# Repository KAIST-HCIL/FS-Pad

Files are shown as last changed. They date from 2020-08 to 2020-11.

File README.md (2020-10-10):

# FS-Pad
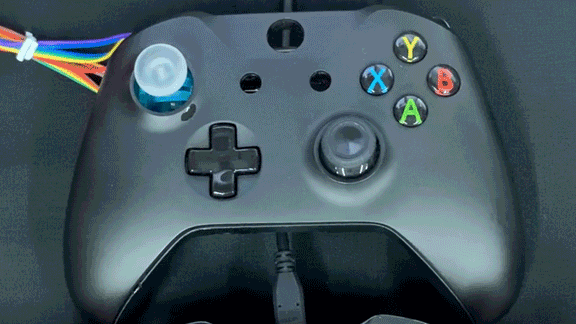
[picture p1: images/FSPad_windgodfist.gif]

<br>
**FS-Pad** is a gamepad with a force feedback thumbstick module.
<br>
You can now feel the external force through your hands when your car crashes, when your avatar gets attacked by an enemy, or when you fire a giant bazooka.
<br>
This is an open source project. Anyone can customize, test, and play with these tiny modules.

  - Video preview: https://youtu.be/CJSe5nMkmYE
  - Game interactions video: https://youtu.be/d1z8tTswZFI
  
This work was presented in [UIST 2020](https://uist.acm.org/uist2020/). You could check out game interaction scenarios & device specification on the paper.

[[Paper]](/FS-Pad.pdf)

## FS Module
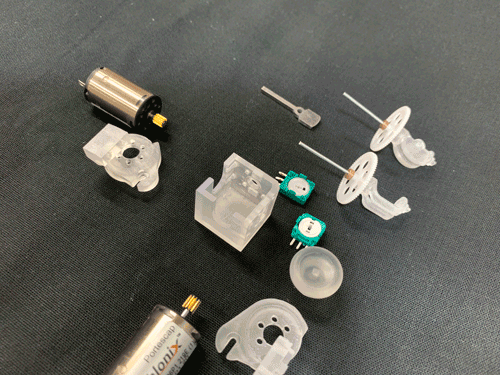
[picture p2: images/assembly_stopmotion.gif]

<br>
Force feedback thumbstick module. The core of the FS-Pad.
<br>
**[Assembly guide](/Assembly%20guide.md)**

## Circuitry
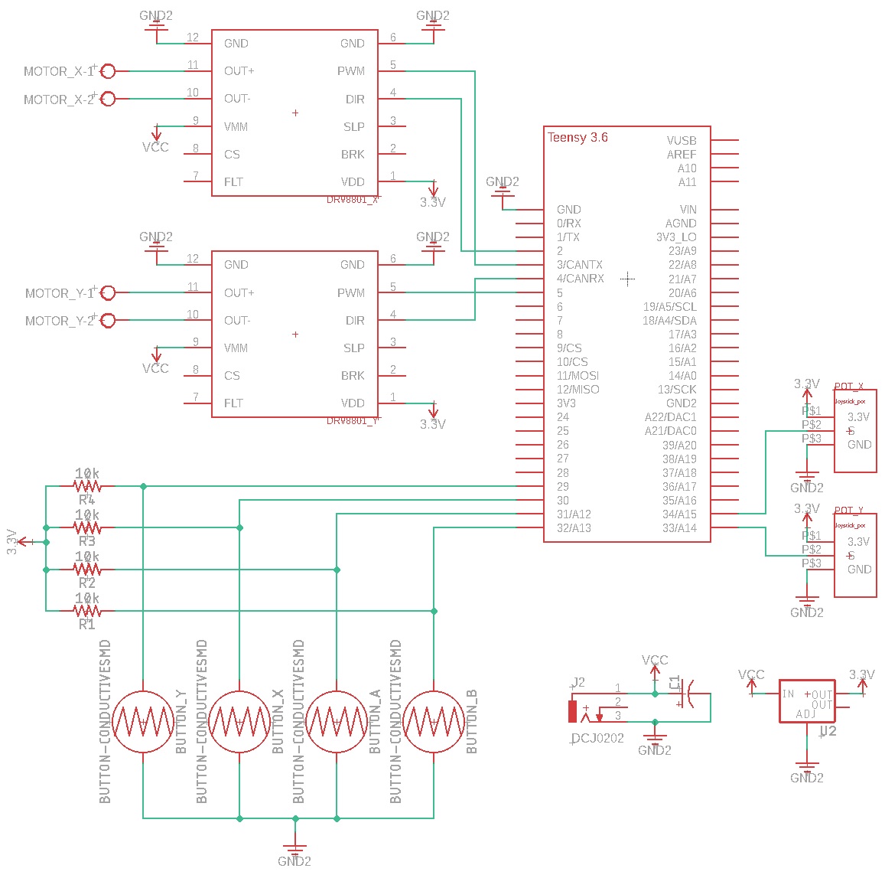
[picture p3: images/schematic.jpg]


  - **Components needed**
    + Teensy 3.6
    + 2 * Motor driver (DRV8801 Breakout board) [[Site]](https://www.pololu.com/product/2136/resources)
    + DC power jack
    + Voltage regulator (LM1117)
    + 4 * 10k Ohm resistors
    + 1 mF capacitor
  - **[Schematic](/circuitry/FSPad_sch.sch)** (Created with Autodesk EAGLE)

## Firmware
**[firmware.ino](/firmware/firmware.ino)**
* Upload the firmware through [Teensyduino](https://www.pjrc.com/teensy/td_download.html).
* You could find out some test scripts and explanations in the [firmware directory](/firmware).

## Announcement
We are currently building a bi-manual version of the FS-Pad; including exclusive housing, custom PCB & schematic, and easy-to-follow documentations. If you have any requests or questions, please directly contact us.

youngbo.shim@kaist.ac.kr

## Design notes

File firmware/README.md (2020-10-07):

# FS-Pad Teensy 3.6 firmware

## Upload the firmware
Upload the firmware to your Teensy through [Teensyduino](https://www.pjrc.com/teensy/td_download.html).

## Calibrating position
Once you set up the hardware, you should update the potentiometer range in the firmware.
- In *firmware.ino*, set *debugMode* as *DEBUG_STICK*
- Open Arduino's Serial monitor.
- Check the raw potentiometer values (0~1023). Record the min/max values of X/Y axes inside your HW configuration's workspace.
- In *firmware.ino*, modify the parameters: *minX, maxX, minY, maxY*.

## Map Test

The map test code [test_forcemaps.py](test_forcemaps.py) can make various kinds of force maps. It shows visualization of a force map and sends it to the Teensy board.

### Quick Start
Below is an example of simulating a spring thumbstick on the FS-Pad.

Be sure to use your port number instead of COM26.

Windows:
```console
$ python -m venv venv
$ venv\Scripts\activate
(venv) $ python -m pip install -r requirements.txt
(venv) $ python .\test_forcemaps.py -f 60 -t spring -p COM26
```
Output:
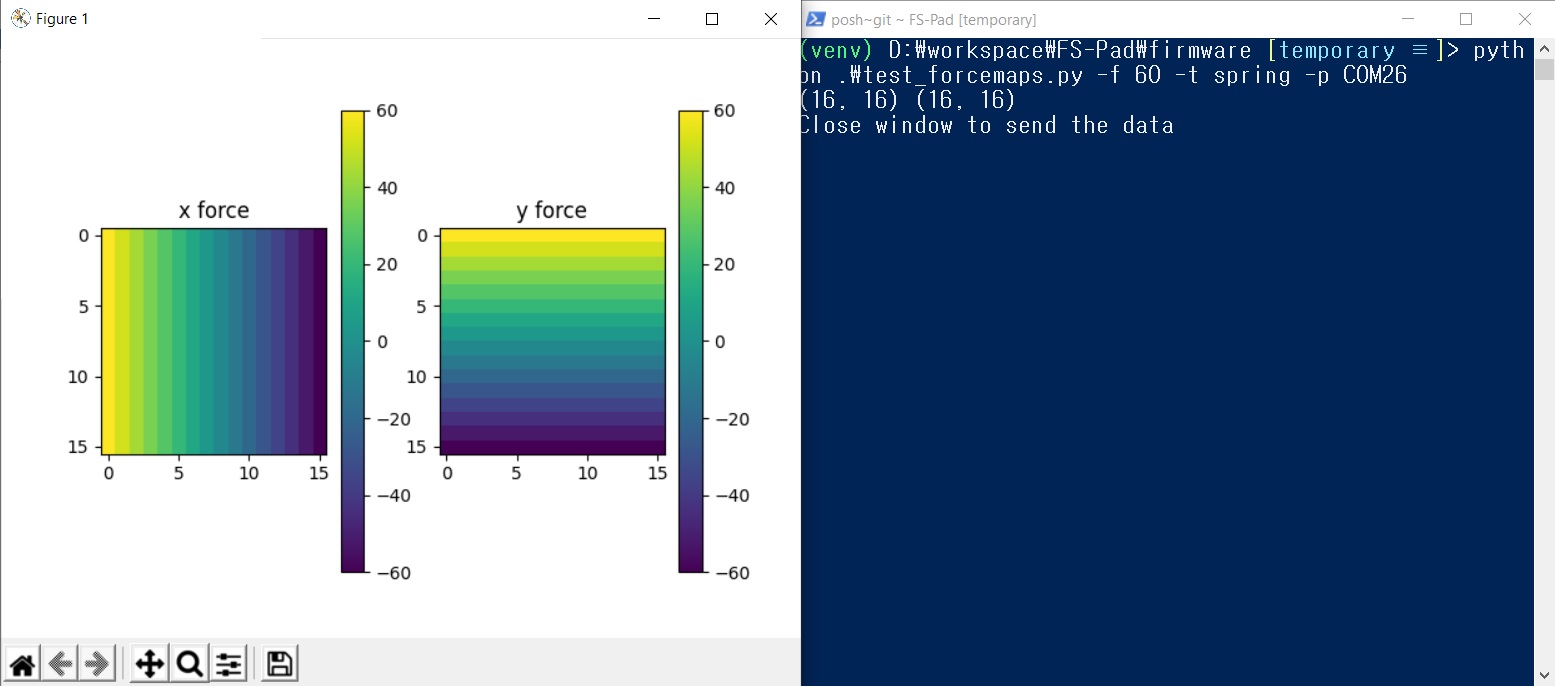
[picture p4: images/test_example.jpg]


You can directly setup your environment instead of using [venv](https://docs.python.org/3/tutorial/venv.html).

## Data format
Every data packet should have a mode indicator byte at the beginning. 'm' is for force map update and 'p' is for force point update.

### Force map
Data should be send as follows. *F* is a list of bytes that contains all data of a force map. *X* is a force map of x direction values and *Y* is for y direction.
Therefore, the size of X and Y is '*# of grid X # of grid*'.
```python
F[0] = X[0,0]
F[1] = Y[0,0]
F[2] = X[0,1]
F[3] = Y[0,1]
.
.
.
F[2*(i*n + j)] = X[i,j]
F[2*(i*n + j)+1] = Y[i,j]
```
The length of F is '*# of grid X # of grid X 2*'. If F is converted to a byte array, the size would be '*# of grid X # of grid X 2 X 4*'. **sizeof(int) == 4 for both Teensy and python**. Teensy reads '*# of grid X # of grid X 2 X 4*' length of bytes when a serial buffer is filled.

If you are not sure how to send data, please see [test_data_send.py](test_data_send.py) or [test_forcemaps.py](test_forcemaps.py).

### Force point
A packet should have the following three values in order.
- force value of x direction
- force value of y direction
- whether to use a saved force map or not (0 = not use, 1 = use)

## Troubleshooting
### Out of RAM
```shell
/home/keunwoo/arduino-1.8.9/arduino-1.8.9/hardware/tools/arm/bin/../lib/gcc/arm-none-eabi/5.4.1/../../../../arm-none-eabi/bin/ld: /tmp/arduino_build_569459/firmware.ino.elf section `.bss' will not fit in region `RAM'
/home/keunwoo/arduino-1.8.9/arduino-1.8.9/hardware/tools/arm/bin/../lib/gcc/arm-none-eabi/5.4.1/../../../../arm-none-eabi/bin/ld: region `RAM' overflowed by 4208 bytes
collect2: error: ld returned 1 exit status
Error compiling for board Teensy 3.6.
```
If you see this kind of error, assign global arrays to *static* ([ref](https://forum.pjrc.com/archive/index.php/t-24449.html)).

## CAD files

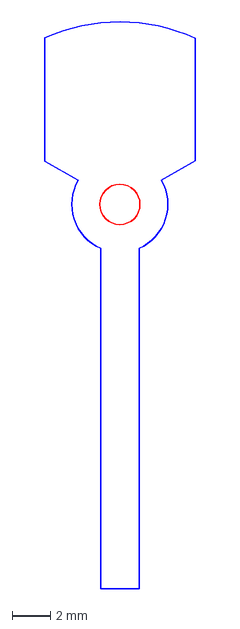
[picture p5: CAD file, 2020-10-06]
CAD files/Stick.dxf
7.82 x 29.8 mm

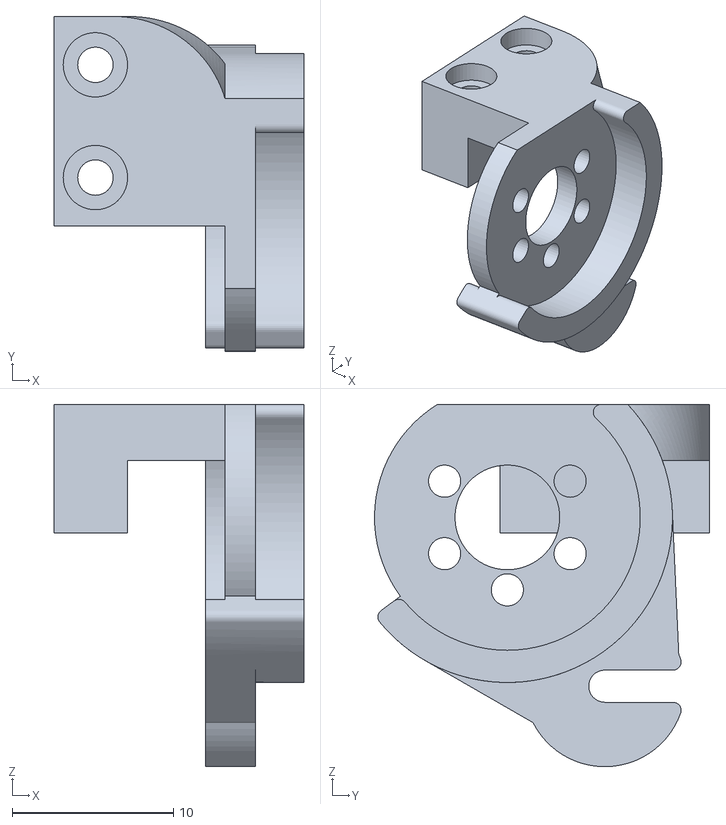
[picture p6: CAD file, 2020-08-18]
CAD files/X axis motor mount.stl
15.5 x 20.8 x 22.5

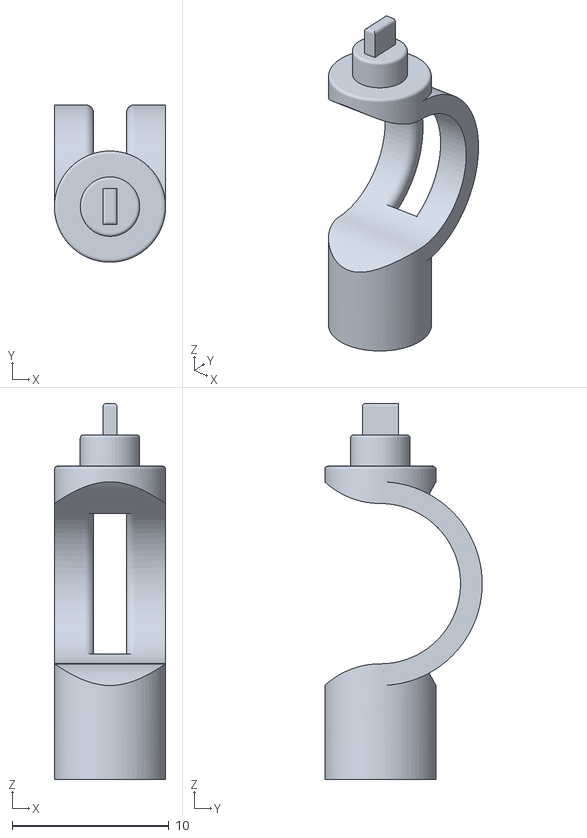
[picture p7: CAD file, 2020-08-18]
CAD files/Y axis guide.stl
7.10 x 10.0 x 24.0

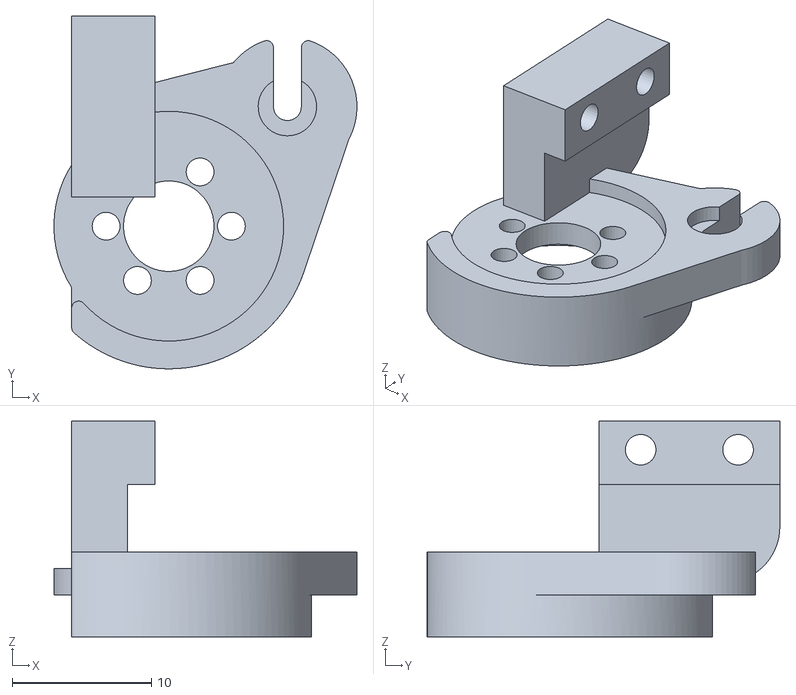
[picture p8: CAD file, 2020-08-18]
CAD files/Y axis motor mount.stl
21.8 x 25.3 x 15.5

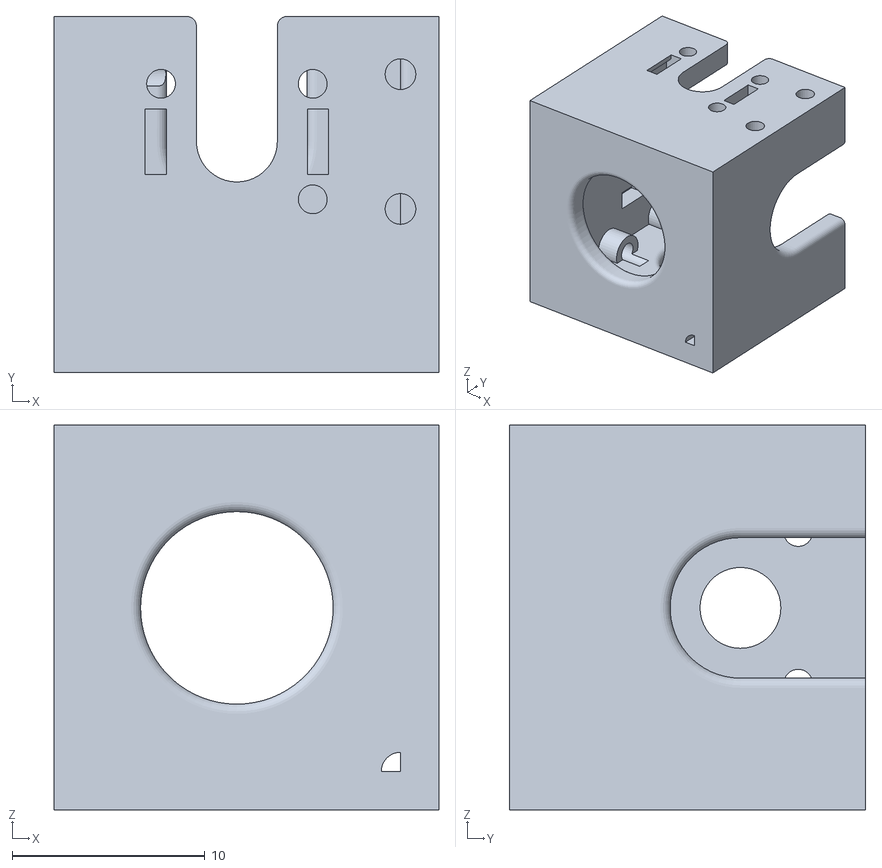
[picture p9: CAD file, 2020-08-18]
CAD files/Module body.stl
20.0 x 18.5 x 20.0

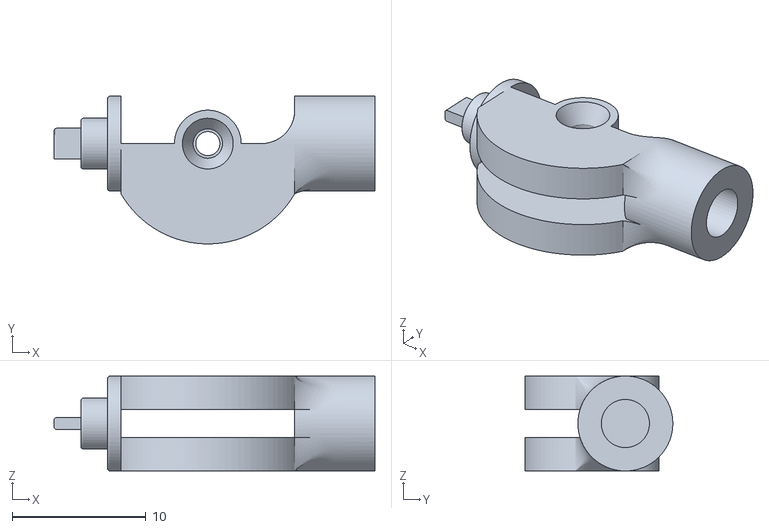
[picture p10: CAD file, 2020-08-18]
CAD files/X axis guide.stl
24.0 x 11.0 x 7.10

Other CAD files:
CAD files/FS Module.f3d

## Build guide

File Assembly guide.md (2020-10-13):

# FS module assembly guide
## Preparation
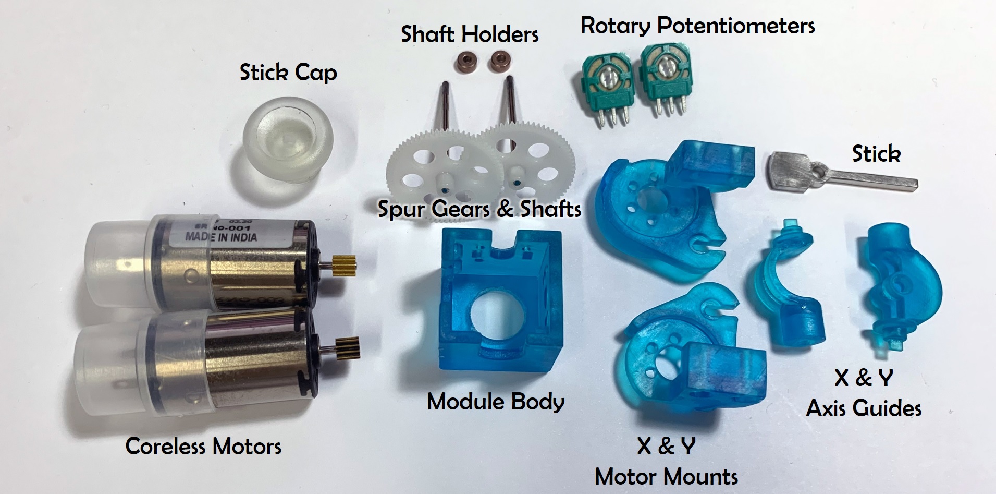
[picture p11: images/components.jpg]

- **Components needed**<br>
Modifying the components will require you to directly modify the CAD files to fit the 3D printable parts.
  + 2 * Coreless motor (16DCT Athlonix 219E) [[Site]](https://www.portescap.com/en/products/brush-dc-motors/athlonix-motors/16dct-athlonix-precious-metal-brush-dc-motor)
  + 2 * Rotary potentiometer (Took apart from a Xbox One controller's thumbstick module)
  + 2 * Large spur gear (70 teeth, modulus 0.3, diameter 21.45 mm, width 1.2 mm) [[Site]](https://ko.aliexpress.com/item/4000099888614.html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,scm-url:1007.14976.178076.0,pvid:82aaac0b-55b4-41d3-aa16-17b92ed123fd,tpp_buckets:668%230%23131923%2358_668%23808%237756%23631_668%23888%233325%2317_4976%230%23178076%230_4976%232711%237538%23352_4976%233223%2310815%237_4976%233104%239653%235_4976%233141%239887%234_668%232846%238116%23949_668%232717%237561%23318__668%233422%2315392%23468)
  + 2 * Small spur gear (11 teeth, modulus 0.3, diameter 3.9 mm, width 4 mm) [[Site]](https://www.aliexpress.com/item/33023736047.html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,searchweb201602_,searchweb201603_)
  + 2 * Shaft M1.5
  + 2 * Shaft holder M1.5
  + 6 * Bolt M1.6 (2.5 mm)
  + 4 * Bolt M2 (10 mm)

<br>

- **Printable parts**<br>
We used a SLA 3D printer ([Form 3](https://formlabs.com/3d-printers/form-3/)). Parts are printed with Tough resin (which is deprecated now by Formlabs) at 0.05 mm resolution. If you use different 3D printers with different settings, you may need some modifications on the CAD file to make a perfect fit for the assembly. Intensive stress is applied to these parts during actuation, so we recommend to use the most durable engineering material for your 3D printer. You could either directly use the .stl files below or export models into printable formats from the Fusion 360 file.
  + [Module body](/CAD%20files/Module%20body.stl)
  + [X axis guide](/CAD%20files/X%20axis%20guide.stl)
  + [X axis motor mount](/CAD%20files/X%20axis%20motor%20mount.stl)
  + [Y axis guide](/CAD%20files/Y%20axis%20guide.stl)
  + [Y axis motor mount](/CAD%20files/Y%20axis%20motor%20mount.stl)
  + **[CAD file](/CAD%20files/FS%20Module.f3d)** (Created with Autodesk Fusion 360)

<br>

- **Stick - laser cut**<br>
We laser cut stainless steel to produce sticks with low friction and durability. You should grind the sharp edges to fit the stick with the components before assembly.
  + [Stick](/CAD%20files/Stick.dxf) (.dxf file)

<br>

- **Tools**<br>
You may need tools listed below while assembling the parts.
  + Screwdriver
  + Tapping tool
  + Rotary tool
  + Instant glue
  + Sandpaper

<br>

## Assembling process
  1. Use the tap to make threads on the module body and X axis guide as indicated below.
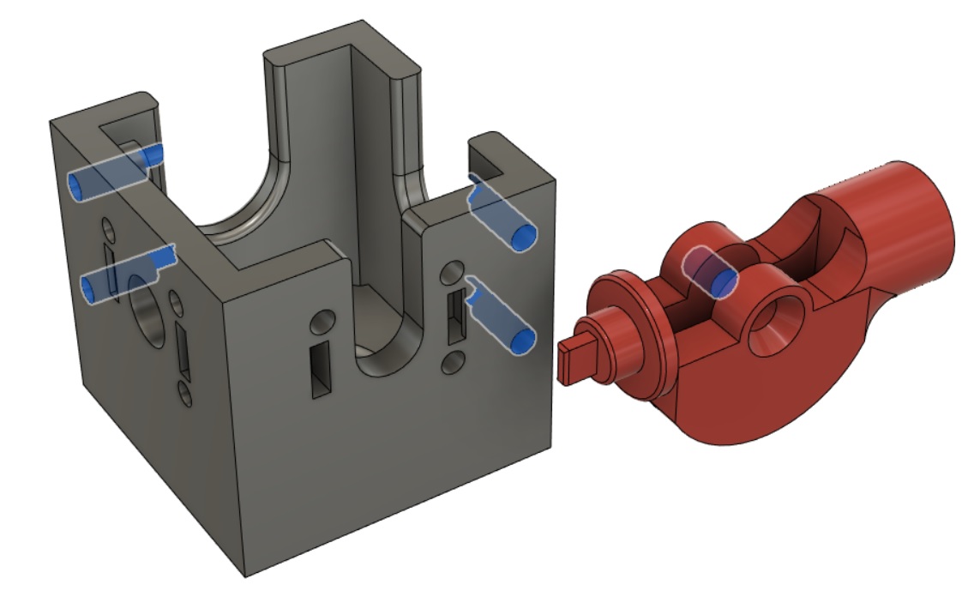
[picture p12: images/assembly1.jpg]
Module body and X axis guide with thread holes indicated.
  
  2. Stick the shafts with the large spur gears, and then attach the gears with the axes guide parts. Note that aligning the shaft and the guide part is important, since this determines the inner friction.
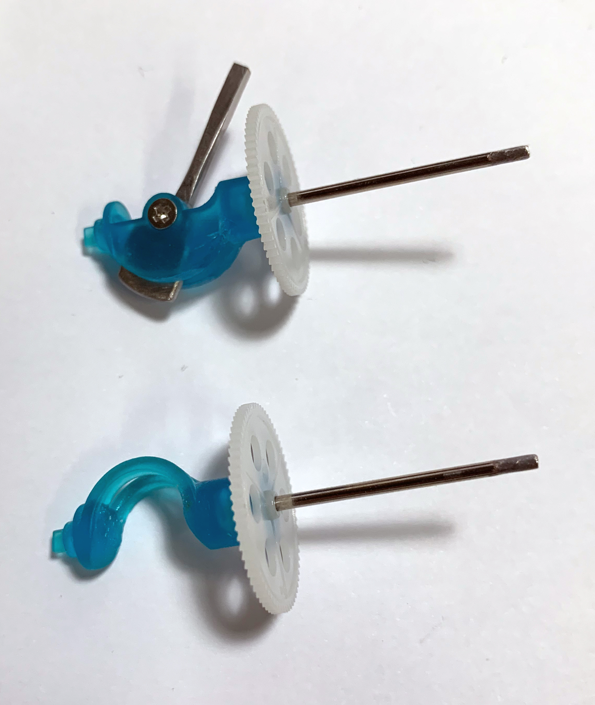
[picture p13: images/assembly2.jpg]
Axes guide parts with large spur gears attached.
  
  3. Install the stick inside the X axis guide (7mm flat M2 bolt). Ensure that the stick moves freely with minimum friction. Try to loosen the bolt or grind the stick if the stick hardly moves.
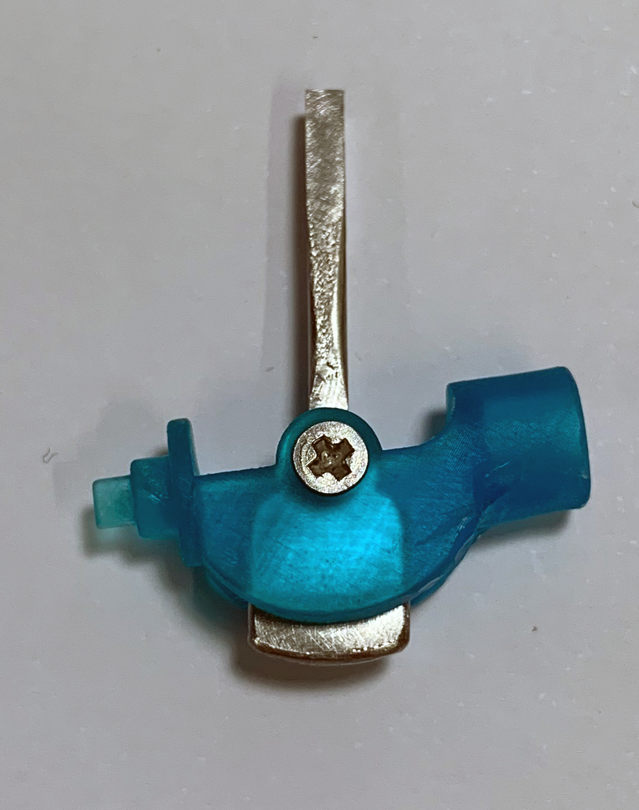
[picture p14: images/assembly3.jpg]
Stick placing inside the X axis guide part.
  
  4. Cross the axes guide parts and fit into the module body.
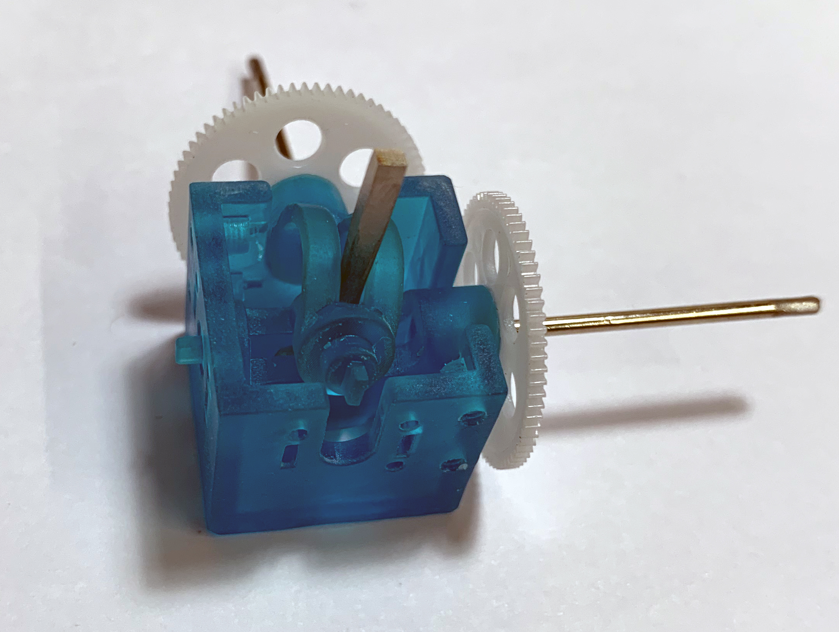
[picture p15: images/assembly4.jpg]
Axes guides fit inside the module body.
  
  5. Push in the potentiometers until they click into the module body. Check if the tips of the axes guides are well inserted.
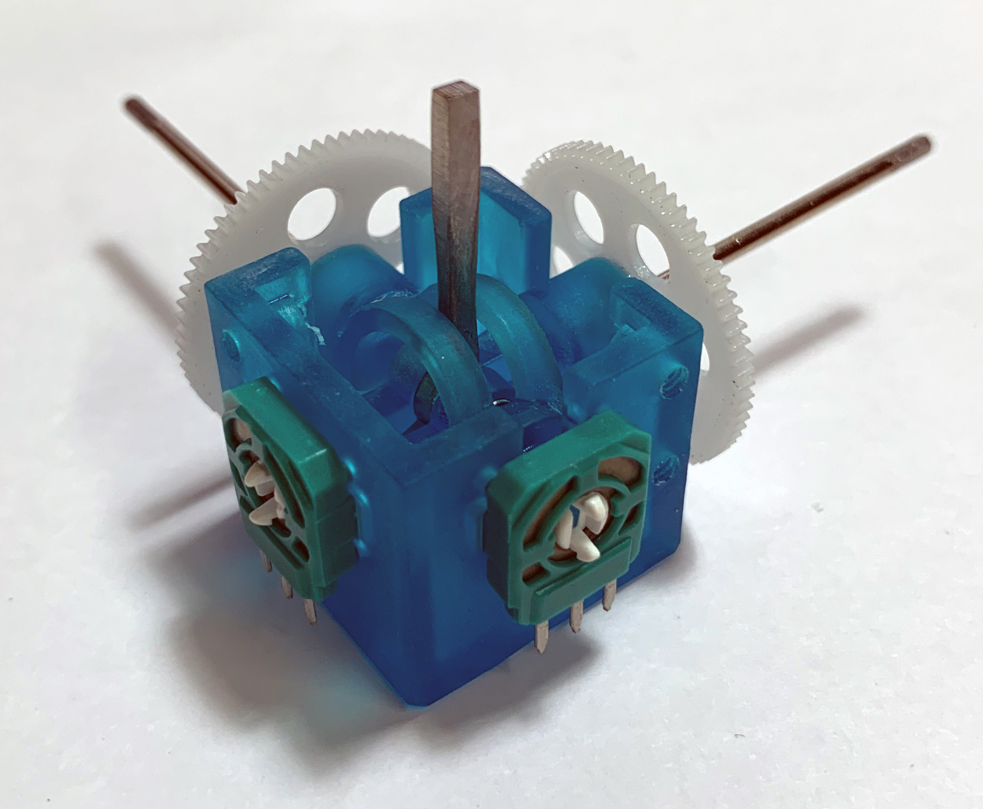
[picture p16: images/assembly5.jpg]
Module body with the potentiometers attached.
  
  6. Connect the motors with the motor mounts (M1.6 bolts).
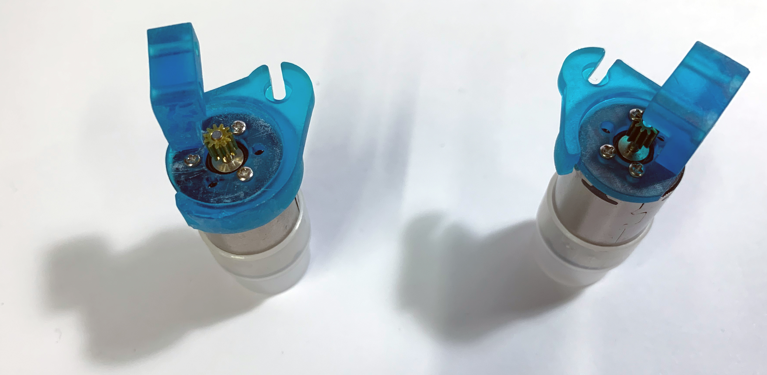
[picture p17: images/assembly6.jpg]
Two motors with motor mounts attached for each.
  
  7. Put the shaft holders first.
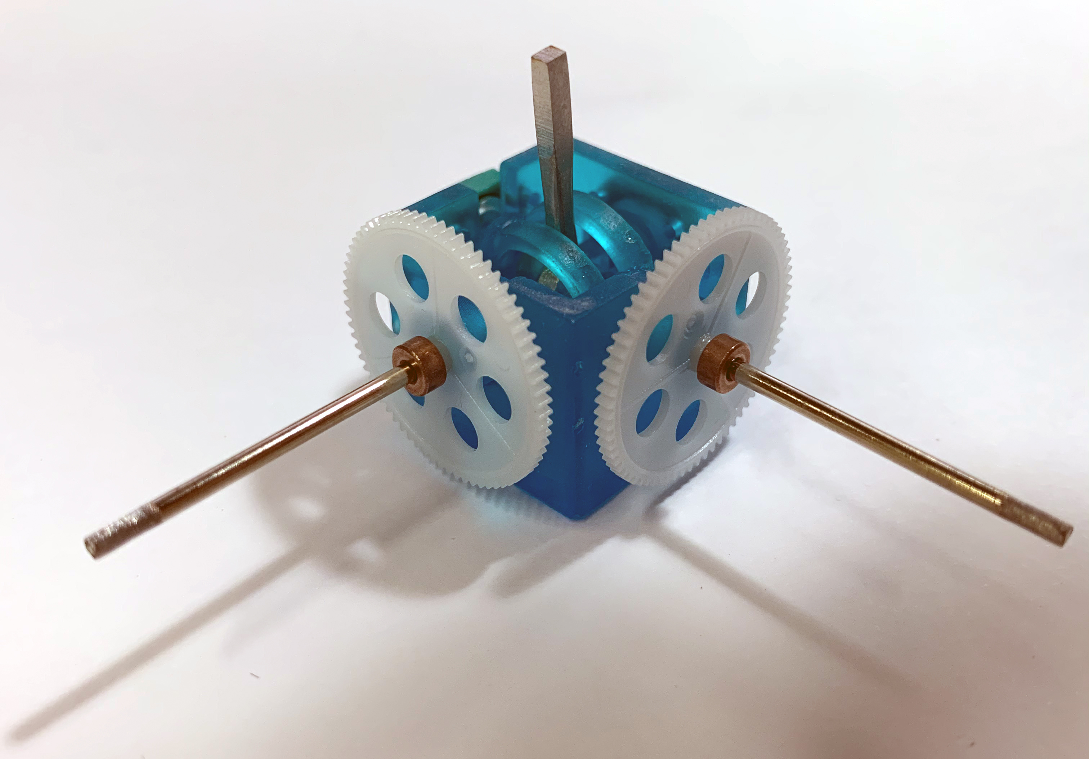
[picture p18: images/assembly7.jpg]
Shaft holders put on the shafts.
  
  8. Connect the motor mounts with the module body (M2 bolts). Check if the stick moves smoothly inside the working space (It may get stuck in diagonal border area inside the module body, but it's OK since the stick won't use that area during actuation).
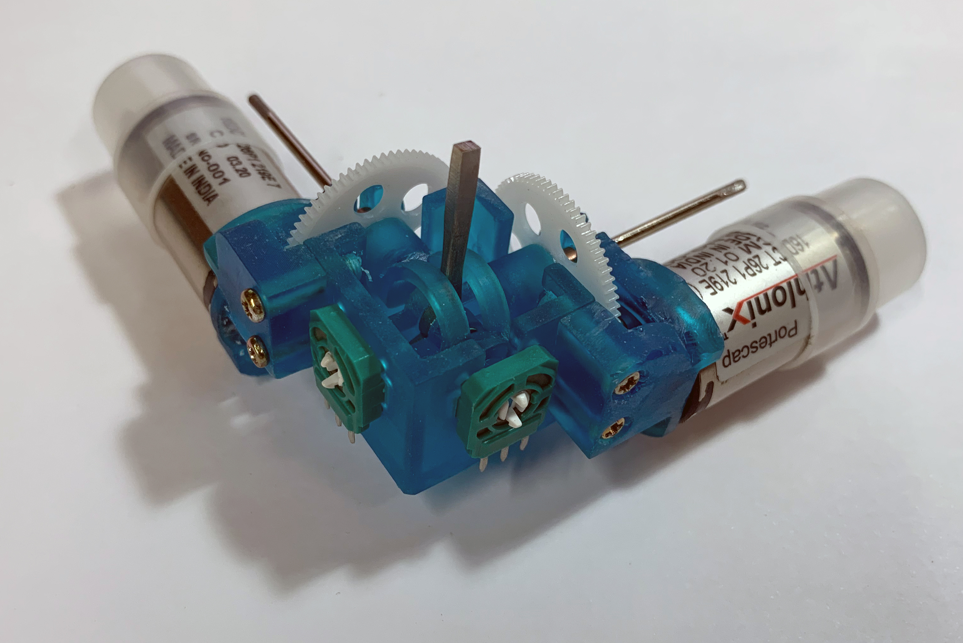
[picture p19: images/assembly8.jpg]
Module body and motors connected.
  
  9. Put the stick cap on.
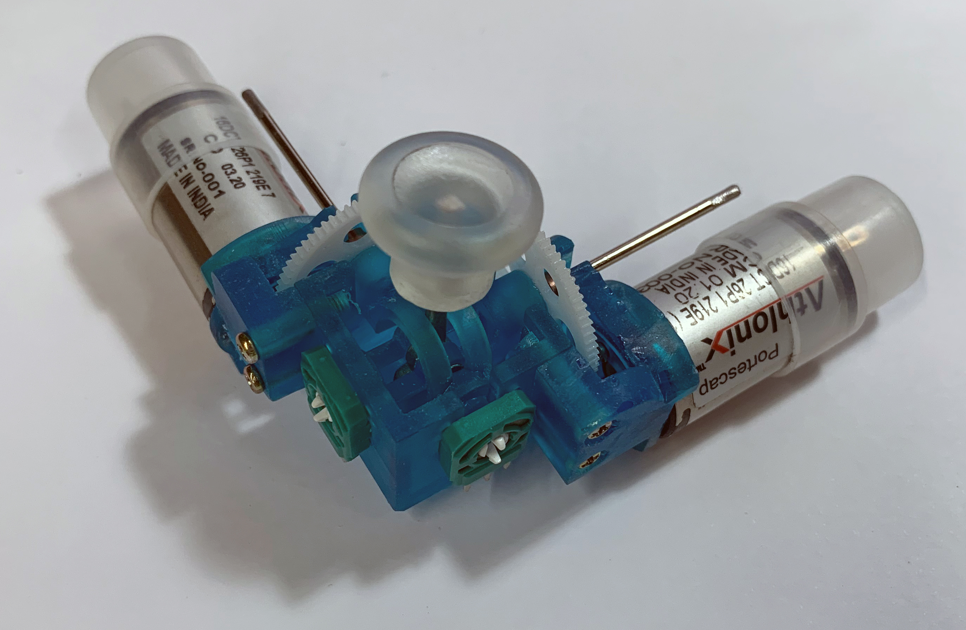
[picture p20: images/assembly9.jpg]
Stick cap added on the module body's stick.


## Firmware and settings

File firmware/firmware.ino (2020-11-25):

#define NO_DEBUG 0
#define DEBUG_RW 1
#define DEBUG_STICK 2
#define SPEED_TEST 3
/*
 ********* PARAMS TO SET*************
*/

const int numGrid = 16;
const int debugMode = NO_DEBUG; // 0: no debug, 1: read/write debug, 2: stick debug
const float minX = 763.0;
const float maxX = 349.0;
const float minY = 686.0;
const float maxY = 240.0;
const float motorXGain = 1.0; // Scales the final output of motor X to balance both motors
const float motorYGain = 0.6; // Scales the final output of motor Y to balance both motors

/**************************/


#include <math.h>

const int vcaXP = 2; // forward vs backward
const int vcaXE = 3; // power (PWM)
const int potXPin = A15;
const int vcaYP = 4; // forward vs backward
const int vcaYE = 5; // power (PWM)
const int potYPin = A14;

// button pins
const int btnAPin = 31;
const int btnBPin = 32;
const int btnXPin = 30;
const int btnYPin = 29;


const int mapSize = numGrid * numGrid * 2 * sizeof(byte); // sizeof(byte) = 1 byte;
const int vectorSize = sizeof(byte) * 2;
const int numVectorInMap = mapSize / vectorSize;

typedef union force_map
{
  byte buf[mapSize];
  byte grid[numGrid][numGrid][2];
};

const int pointSize = sizeof(uint8_t) * 3;
typedef union force_point
{
  struct
  {
    byte x;
    byte y;
    byte useMap;
  } value;
  byte buf[pointSize];
};

static force_map forceMap;
static force_point forcePoint;

// code protocol
const char mapCode = 'm';
const char pointCode = 'p';
const char successCode = 's';

// value holders
int potXPos = 0;
int potYPos = 0;
int forceXP = 0;
int forceXE = 0;
int forceYP = 0;
int forceYE = 0;
int stickMode = 1;
// posistion values, -1~1
float posX = 0;
float posY = 0;
// button states. pressed : 1, not pressed : 0
int btnA = 0;
int btnB = 0;
int btnX = 0;
int btnY = 0;

// time checker for serial output rate
long timepassed = 0;
long serOutRate = 250; // 250Hz
bool stringComplete = false;

// prev pot value for damping
int prevPotX = -1000;
int prevPotY = -1000;

void setup() {

  pinMode(vcaXP, OUTPUT);
  pinMode(vcaXE, OUTPUT);
  pinMode(vcaYP, OUTPUT);
  pinMode(vcaYE, OUTPUT);

  pinMode(btnAPin, INPUT);
  pinMode(btnXPin, INPUT);
  pinMode(btnYPin, INPUT);
  pinMode(btnBPin, INPUT);

  // Modify PWM frequency & resolution
  analogWriteFrequency(vcaXE, 20000); // pwm freq: 20kHz (lower than teensy freq.'s half), 50kHz made noise
  analogWriteFrequency(vcaYE, 20000);
  analogWriteResolution(7); // pwm value range: 0~127

  for (int i = 0; i < numGrid; i++) {
    for (int j = 0; j < numGrid; j++) {
      forceMap.grid[i][j][0] = 0;
      forceMap.grid[i][j][1] = 0;
    }
  }

  forcePoint.value.x = 0;
  forcePoint.value.y = 0;
  forcePoint.value.useMap = 1;


  Serial.begin(115200);
  while (!Serial);

  timepassed = micros();
}

void loop() {

  char code = '?';

  if (Serial.available())
  {
    code = Serial.read();
  }

  if (code == mapCode)
  {
    updateForceMap();
  }
  else if (code == pointCode)
  {
    updateForcePoint();
  }

  updateButtons();
  updateStick();

  if (micros() - timepassed > pow(10, 6) / serOutRate)
  {
    sendControllerState();
    timepassed = micros();
  }
}


void updateButtons()
{
  btnA = getButtonPressed(btnAPin);
  btnB = getButtonPressed(btnBPin);
  btnX = getButtonPressed(btnXPin);
  btnY = getButtonPressed(btnYPin);
}

int getButtonPressed(int pin)
{
  int val = digitalRead(pin);
  if (val == 0) // LOW
  {
    return 1;
  }
  else // HIGH
  {
    return 0;
  }
}

void updateStick()
{
  int potX = analogRead(potXPin); // raw potentiometer value (0~1024)
  int potY = analogRead(potYPin);
  int dX;
  int dY;

  posX = pot2PosX(potX);  // convert raw pot value to position value (0~numGrid-1)
  posY = pot2PosY(potY);

  // Apply force point's value
  int forceX = ubyte2sint(forcePoint.value.x);
  int forceY = ubyte2sint(forcePoint.value.y);

  // Apply force map's value if available.
  // calculates the interpolated vector of surrounding 4 grids.
  if (forcePoint.value.useMap)
  {
    interpForceMap(posX, posY, forceX, forceY); // forceX is PWM value, 0 to 127

    /*
    if(prevPotX == -1000){
      prevPotX = potX;
      dX = -1000;
    }
    else{
      dX = potX - prevPotX;
      prevPotX = potX;
    }
    if(prevPotY == -1000){
      prevPotY = potY;
      dY = -1000;
    }
    else{
      dY = potY - prevPotY;
      prevPotY = potY;
    }

    raw_damping(dX, dY,&forceX, &forceY);
    */
  }

  if (debugMode == DEBUG_STICK)
  {

    Serial.print(potX);
    Serial.print(',');
    Serial.print(potY);
    Serial.print(',');

    Serial.print(posX);
    Serial.print(',');
    Serial.print(posY);
    Serial.print('\n');
    delay(100);
  }
  else if (debugMode == NO_DEBUG)
  {
    forceStickX(forceX);
    forceStickY(forceY);
  }
}

void updateForcePoint()
{
  if (Serial.available())
  {
    Serial.readBytes((char*) forcePoint.buf, pointSize);

    if (debugMode == DEBUG_RW)
    {
      Serial.print(forcePoint.value.x);
      Serial.print(',');
      Serial.print(forcePoint.value.y);
      Serial.print(',');
      Serial.print(forcePoint.value.useMap);
      Serial.print('\n');
    }
    else if (debugMode == SPEED_TEST)
    {
      Serial.write('s');
    }
  }
}

void updateForceMap()
{
  if (Serial.available())
  {
    Serial.readBytes((char*) forceMap.buf, mapSize);

    if (debugMode == DEBUG_RW)
    {
      for (int i = 0; i < numVectorInMap; i++)
      {
        int row = i / numGrid;
        int col = i - row * numGrid;
        Serial.print(row);
        Serial.print(',');
        Serial.print(col);
        Serial.print(',');
        Serial.print(forceMap.grid[row][col][0]);
        Serial.print(',');
        Serial.print(forceMap.grid[row][col][1]);
        Serial.print('\n');
      }
    }
    else if (debugMode == SPEED_TEST)
    {
      Serial.write('s');
    }
  }
}

float filterX(float delta){ // filter for X value for dead zone
  if(delta < 1.5 && delta >-1.5){
    return 0;
  }
  else{
    return delta;
  }
}

float filterY(float delta){ // filter for Y value for dead zone
  if(delta < 3 && delta >-3){
    return 0;
  }
  else{
    return delta;
  }
}

void raw_damping(float dX, float dY, int* forceX, int* forceY){ //raw_damping(dX, dY, &forceX, &forceY);
  if(dX != -1000){
    *forceX -= 10 * filterX(dX);
  }
  if(dY != -1000){
    *forceY -= 12 * filterY(dY);
  }
}

void sendControllerState()
{
  if (debugMode == NO_DEBUG)
  {
    char line[18];
    sprintf(line, "%.2f,%.2f,%d,%d,%d,%d\n", posX, posY, btnA, btnB, btnX, btnY);
    Serial.print(line);
  }
}

int ubyte2sint(byte val)
{
  return (int)(-(val & 0x80) + (val & 0x7F));
}

float pot2PosX(float potVal)
{
  // float posVal = -0.0044 * potVal + 2.0911;
  float posVal = 2 / (maxX - minX) * potVal + (minX + maxX) / (minX - maxX);
  if (posVal > 1)
    posVal = 1;
  else if (posVal < -1)
    posVal = -1;
  return -posVal;
}

float pot2PosY(float potVal)
{
  // float posVal = -0.0049 * potVal + 2.6422;
  float posVal = 2 / (maxY - minY) * potVal + (minY + maxY) / (minY - maxY);
  if (posVal > 1)
    posVal = 1;
  else if (posVal < -1)
    posVal = -1;
  return -posVal;
}

void interpForceMap(float x, float y, int& outputX, int& outputY)
{
  float gridCoordX = (numGrid - 1) / 2 * x + (numGrid - 1) / 2;
  float gridCoordY = (numGrid - 1) / 2 * y + (numGrid - 1) / 2;
  int floorX = (int)floor(gridCoordX);
  int floorY = (int)floor(gridCoordY);
  float ratioX = gridCoordX - (float)floorX;
  float ratioY = gridCoordY - (float)floorY;
  int ceilX = floorX > 15 ? floorX : floorX + 1;
  int ceilY = floorY > 15 ? floorY : floorY + 1;
  floorX = floorX < 0 ? 0 : floorX;
  floorY = floorY < 0 ? 0 : floorY;

  // bilinear interpolation
  outputX += ubyte2sint(forceMap.grid[floorX][floorY][0]) * (1 - ratioX) * (1 - ratioY) +
             ubyte2sint(forceMap.grid[floorX][ceilY][0]) * (1 - ratioX) * ratioY +
             ubyte2sint(forceMap.grid[ceilX][floorY][0]) * ratioX * (1 - ratioY) +
             ubyte2sint(forceMap.grid[ceilX][ceilY][0]) * ratioX * ratioY;
  outputY += ubyte2sint(forceMap.grid[floorX][floorY][1]) * (1 - ratioX) * (1 - ratioY) +
             ubyte2sint(forceMap.grid[floorX][ceilY][1]) * (1 - ratioX) * ratioY +
             ubyte2sint(forceMap.grid[ceilX][floorY][1]) * ratioX * (1 - ratioY) +
             ubyte2sint(forceMap.grid[ceilX][ceilY][1]) * ratioX * ratioY;

  return;
}

void forceStickX(int val)
{
  val = (int)((float)val * motorXGain);
  forceStick(vcaXP, vcaXE, val, HIGH);
}

void forceStickY(int val)
{
  val = (int)((float)val * motorYGain);
  forceStick(vcaYP, vcaYE, val, HIGH);
}

void forceStick(int phasePin, int enablePin, int val, int plusPhase)
{
  int absVal = 0;
  int minusPhase = LOW;
  if (plusPhase == LOW)
  {
    minusPhase = HIGH;
  }

  if (val < 0)
  {
    digitalWrite(phasePin, minusPhase);
    absVal = abs(val);
  }
  else
  {
    digitalWrite(phasePin, plusPhase);
    absVal = val;
  }
  analogWrite(enablePin, absVal);
}

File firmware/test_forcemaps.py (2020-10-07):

import serial
import struct
import numpy as np
import matplotlib.pyplot as plt
import time
import argparse
import sys


def parse_args():
    parser = argparse.ArgumentParser()

    parser.add_argument('-m', '--map-size', type=int, default=16,
                        help="Number of grids for the force map.")
    parser.add_argument('-f', '--force', type=int,
                        help="Max force value to use. Negative of \
                        this value is used for min force value. 0~255",
                        required=True)
    parser.add_argument('-t', '--map-type', type=str,
                        choices=['spring', 'blackhole', 'whitehole', 'wall'],
                        help="Choose which force map to use.", required=True)
    parser.add_argument('-p', '--port', type=str, help="USB port name.")
    parser.add_argument('-b', '--baud-rate', type=int,
                        default=115200, help="Baudrate of USB.")
    parser.add_argument('--debug', action='store_true',
                        help="Print output of Teensy")
    parser.add_argument('--test-point', action='store_true',
                        help="Test force point sending")

    if not len(sys.argv) > 1:
        parser.print_help()
        sys.exit(-1)

    return parser.parse_args()


def send_map(ser, force_map):
    flat_data = np.array(force_map, dtype=np.int8).flatten().tolist()
    pack_pattern = '<'+'b'*len(flat_data)
    bytes_to_write = struct.pack(pack_pattern, *flat_data)
    bytes_to_write = b'm' + bytes_to_write
    ser.write(bytes_to_write)


def send_point(ser, x, y, use_map=1):
    data = [x, y, use_map]
    pack_pattern = '<'+'b'*len(data)
    bytes_to_write = struct.pack(pack_pattern, *data)
    bytes_to_write = b'p' + bytes_to_write
    ser.write(bytes_to_write)
    """
    while True:
        recv = ser.read()
        if(recv == b's'):
            break
    """


def join_as_map(x_data, y_data):
    X = np.expand_dims(np.array(x_data), axis=2)
    Y = np.expand_dims(np.array(y_data), axis=2)
    F = np.concatenate((X, Y), axis=2)
    """
        format of F:

        F[0] = X[0,0]
        F[1] = Y[0,0]
        F[2] = X[0,1]
        F[3] = Y[0,1]
        .
        .
        .
        F[2*(i*n + j)] = X[i,j]
        F[2*(i*n + j)+1] = Y[i,j]
    """
    return F


def create_map(map_type, min_val, max_val, n_grid):
    if map_type == "spring":
        return create_spring_map(min_val, max_val, n_grid)
    if map_type == "blackhole":
        return create_blackhole_map(min_val, max_val, n_grid)
    if map_type == "whitehole":
        return create_whthole_map(min_val, max_val, n_grid)
    if map_type == "wall":
        return create_wall_map(min_val, max_val, n_grid)


def create_spring_map(min_val, max_val, n_grid):
    # range of x and y should be 0 to 1
    x = np.linspace(1, 0, n_grid)
    y = np.linspace(1, 0, n_grid)
    xv, yv = np.meshgrid(x, y)

    xv = xv * (max_val - min_val) + min_val
    yv = yv * (max_val - min_val) + min_val
    xv.astype(int)
    yv.astype(int)

    return xv, yv


def create_blackhole_map(min_val, max_val, n_grid):

    dist = np.linspace(-1, 1, n_grid)
    x = -dist**3
    y = -dist**3
    xv, yv = np.meshgrid(x, y)

    xv = xv * (max_val)
    yv = yv * (max_val)
    xv.astype(int)
    yv.astype(int)

    return xv, yv


def create_whthole_map(min_val, max_val, n_grid):

    dist = np.linspace(-1, 1, n_grid)
    x = dist**3
    y = dist**3
    xv, yv = np.meshgrid(x, y)

    xv = xv * (max_val)
    yv = yv * (max_val)
    xv.astype(int)
    yv.astype(int)

    return xv, yv


def create_wall_map(min_val, max_val, n_grid):

    # range of x and y should be 0 to 1
    x = np.zeros(n_grid)
    x[:int(n_grid / 2)] = [max_val] * int(n_grid / 2)
    y = np.zeros(n_grid)

    xv, yv = np.meshgrid(x, y)

    xv.astype(int)
    yv.astype(int)

    return xv, yv


def show(xv, yv):

    plt.subplot(121)
    plt.imshow(xv)
    plt.title("x force")
    plt.colorbar()
    plt.subplot(122)
    plt.imshow(yv)
    plt.title("y force")
    plt.colorbar()

    print("Close window to send the data")
    plt.show()


def main(args):
    map_size = args.map_size
    min_force = -args.force
    max_force = args.force
    rowv, colv = create_map(args.map_type, min_force, max_force, map_size)
    print(rowv.shape, colv.shape)
    show(rowv, colv)

    # for the force map, meshgrid should be flpped
    fx = colv
    fy = rowv

    force_map = join_as_map(fx, fy)
    ser = serial.Serial(args.port, args.baud_rate, timeout=1)
    send_map(ser, force_map)

    send_point_toggle = True
    use_map = 1
    while True:
        # time.sleep(0.1)
        if args.test_point:
            if not args.debug:
                time.sleep(0.1)
            if send_point_toggle:
                send_point(ser, int(max_force / 2),
                           int(max_force / 2), use_map=use_map)
                send_point_toggle = False
            else:
                send_point(ser, 0, 0, use_map=use_map)
                send_point_toggle = True

        if args.debug:
            recv = ser.readline()
            if recv:
                print(recv)

        if not args.debug and not args.test_point:
            break

    ser.close()


if __name__ == '__main__':
    args = parse_args()
    main(args)

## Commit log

2020-08-18 Update CAD files
    [FS Module.f3d, FS module Xbox fit v25.f3d, Module body.stl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]
2020-08-18 Writing assembly guide
2020-08-19 Temporary update Assembly guide.md
2020-08-19 Update Assembly guide.md & images
2020-08-19 Update Assembly guide.md (image arrange)
2020-08-19 Add Stick.dxf
    [Stick.dxf]
2020-08-26 Update Assembly guide.md
2020-10-06 Add pot calibration parameters
2020-10-06 Update pot calibration guide & minor typos
2020-10-07 Add motor balance parameters
